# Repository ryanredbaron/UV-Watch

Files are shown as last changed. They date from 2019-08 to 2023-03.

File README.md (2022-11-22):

# UV Watch
## Current MVP
- 10 hours of battery
- Track UV/% burned
- Close enough battery tracking
 
## Project List
1. [x] Clock refinement 
2. [x] Battery shut off
3. [x] Sunscreen apply
4. [ ] Sun reset
5. [x] Less sensitive to sun 
6. [?] Uv sensor voltage revamp
7. [x] Low power mode
8. [x] Input time from PC

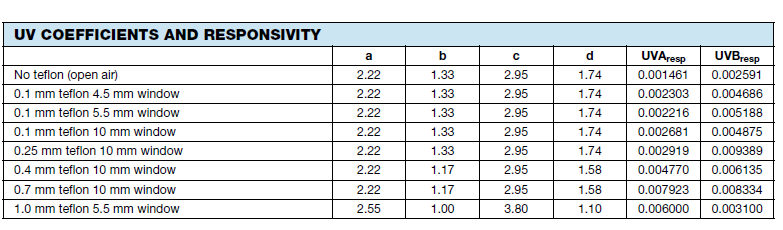
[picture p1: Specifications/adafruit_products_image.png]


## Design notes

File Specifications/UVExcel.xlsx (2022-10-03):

UV | TTB Min | TTB sec |  | y = -267.48x + 3913.6
0 | 60 | 3600 | 1000 | 27.77777778%
1 | 60 | 3600 | 1000 | 27.77777778%
2 | 60 | 3600 | 1000 | 27.77777778%
3 | 40 | 2400 | 1000 | 41.66666667%
4 | 40 | 2400 | 1000 | 41.66666667%
5 | 40 | 2400 | 1000 | 41.66666667%
6 | 30 | 1800 | 1000 | 55.55555556%
7 | 30 | 1800 | 1000 | 55.55555556%
8 | 20 | 1200 | 1000 | 83.33333333%
9 | 20 | 1200 | 1000 | 83.33333333%
10 | 20 | 1200 | 1000 | 83.33333333%
11 | 15 | 900 | 1000 | 111.1111111%
UV | TTB Sec
0 | 3913.6
1 | 3646.12 | 121.5373333
2 | 3378.64
3 | 3111.16
4 | 2843.68
5 | 2576.2
6 | 2308.72
7 | 2041.24
8 | 1773.76
9 | 1506.28
10 | 1238.8
11 | 971.32
12 | 703.84
30

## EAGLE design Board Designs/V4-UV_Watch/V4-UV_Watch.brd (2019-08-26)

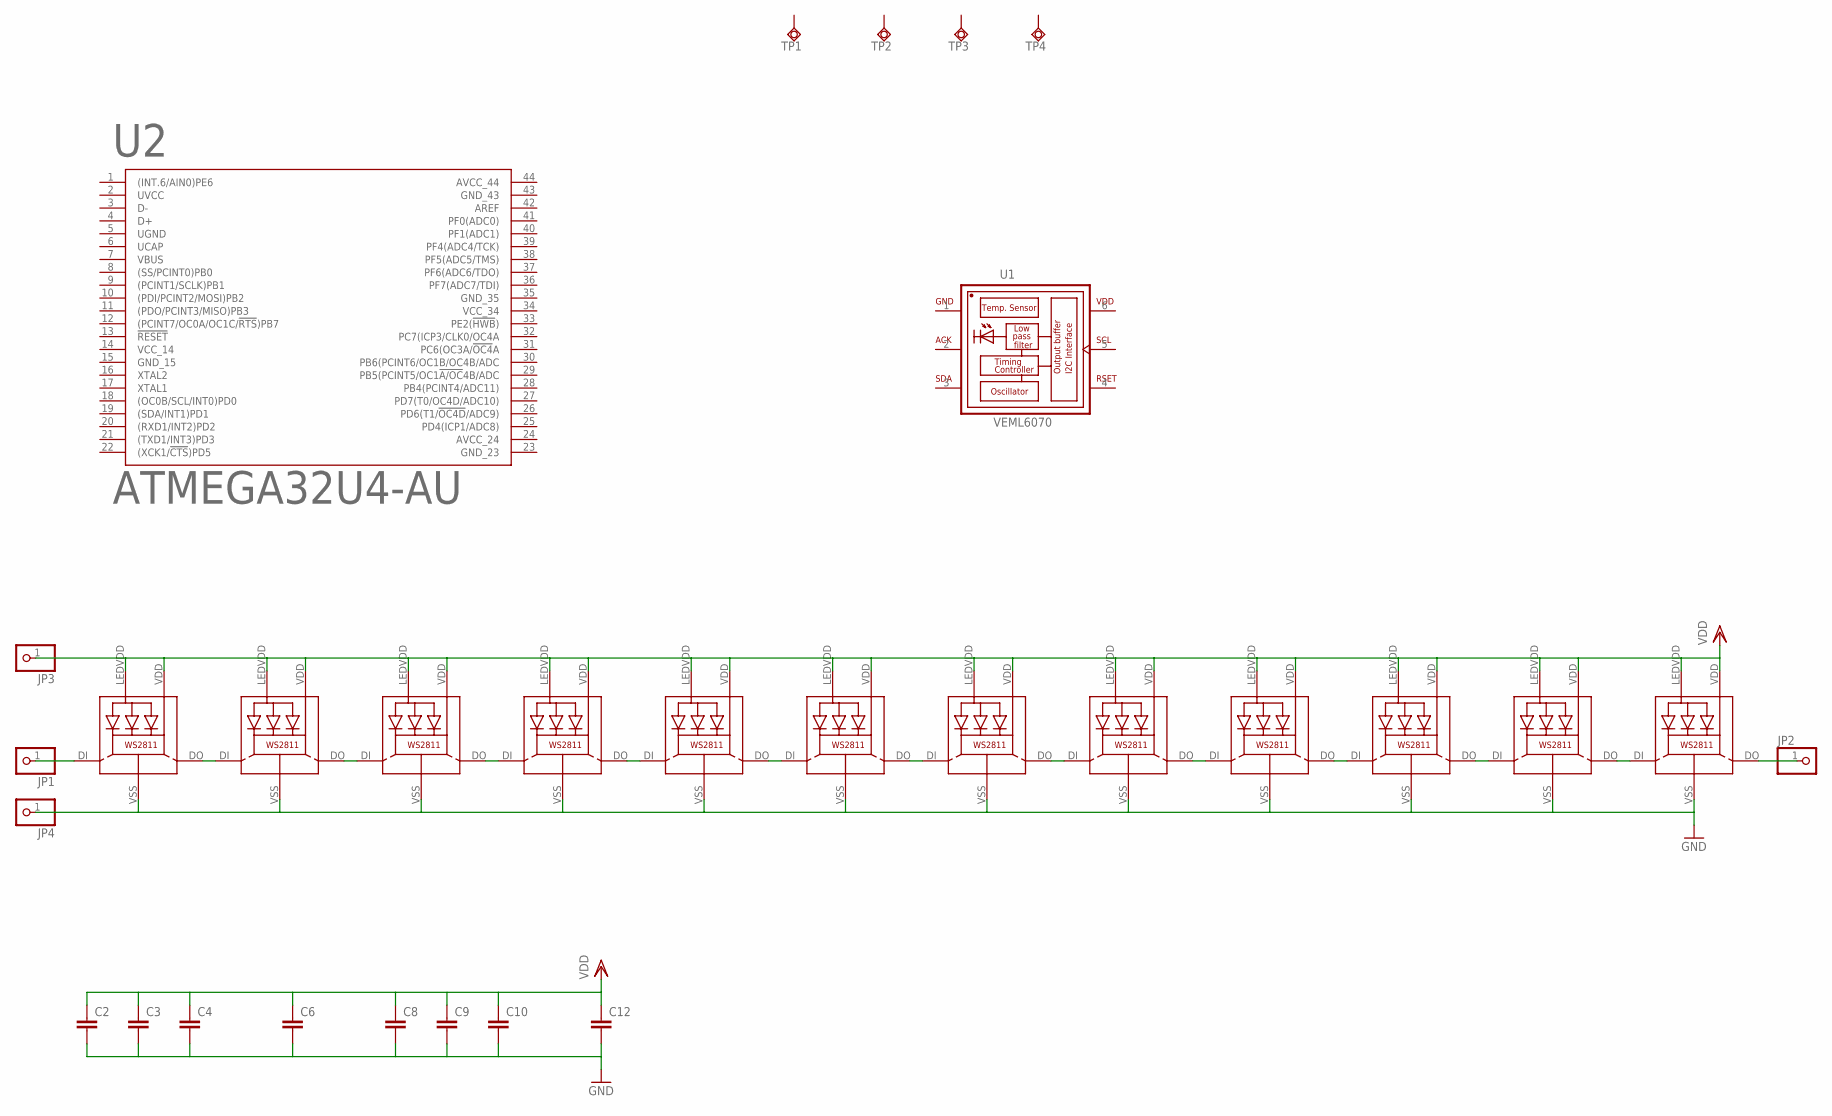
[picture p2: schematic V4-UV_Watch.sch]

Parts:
C2, C3, C4, C6, C8, C9, C10, C12: C-EUC0603; C0603
JP1, JP2, JP3, JP4: PINHD-1X1CB; 1X01-CLEANBIG
LED1, LED2, LED3, LED4, LED5, LED6, LED7, LED8, LED9, LED10, LED11, LED12: WS28115050
TP1, TP2, TP3, TP4: TESTPAD_TPSQTP20SQ; TESTPAD_TP20SQ
U1: VEML6070; PHODET_VEML6070
U2: ATMEGA32U4-AU; 44-TQFP

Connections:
AVCC_24: U2.24 (AVCC_24)
AVCC_44: U2.44 (AVCC_44)
GND: C2.2, C3.2, C4.2, C6.2, C8.2, C9.2, C10.2, C12.2, JP4.1, LED1.VSS (GND), LED2.VSS (GND), LED3.VSS (GND), LED4.VSS (GND), LED5.VSS (GND), LED6.VSS (GND), LED7.VSS (GND), LED8.VSS (GND), LED9.VSS (GND), LED10.VSS (GND), LED11.VSS (GND), LED12.VSS (GND), U1.1 (GND)
GND_15: U2.15 (GND_15)
GND_23: U2.23 (GND_23)
GND_35: U2.35 (GND_35)
GND_43: U2.43 (GND_43)
unnamed: LED1.DO, LED2.DI
unnamed: LED2.DO, LED3.DI
unnamed: LED3.DO, LED4.DI
unnamed: LED4.DO, LED5.DI
unnamed: LED5.DO, LED6.DI
unnamed: LED6.DO, LED7.DI
unnamed: LED7.DO, LED8.DI
unnamed: LED8.DO, LED9.DI
unnamed: LED9.DO, LED10.DI
unnamed: LED10.DO, LED11.DI
unnamed: LED11.DO, LED12.DI
unnamed: JP1.1, LED1.DI
unnamed: JP2.1, LED12.DO
UCAP: U2.6 (UCAP)
UGND: U2.5 (UGND)
UVCC: U2.2 (UVCC)
VCC_14: U2.14 (VCC_14)
VCC_34: U2.34 (VCC_34)
VDD: C2.1, C3.1, C4.1, C6.1, C8.1, C9.1, C10.1, C12.1, JP3.1, LED1.LEDVDD, LED1.VDD, LED2.LEDVDD, LED2.VDD, LED3.LEDVDD, LED3.VDD, LED4.LEDVDD, LED4.VDD, LED5.LEDVDD, LED5.VDD, LED6.LEDVDD, LED6.VDD, LED7.LEDVDD, LED7.VDD, LED8.LEDVDD, LED8.VDD, LED9.LEDVDD, LED9.VDD, LED10.LEDVDD, LED10.VDD, LED11.LEDVDD, LED11.VDD, LED12.LEDVDD, LED12.VDD, U1.6 (VDD)

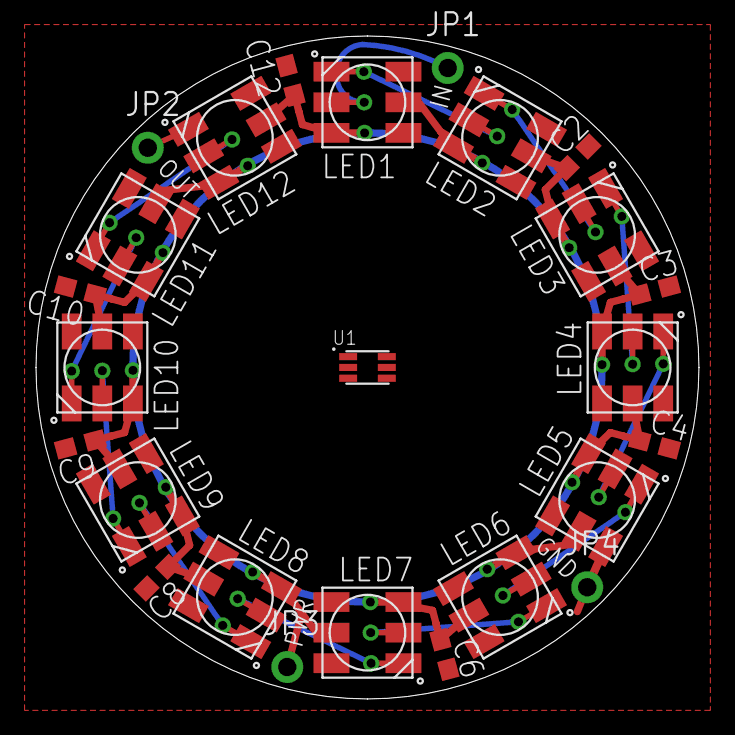
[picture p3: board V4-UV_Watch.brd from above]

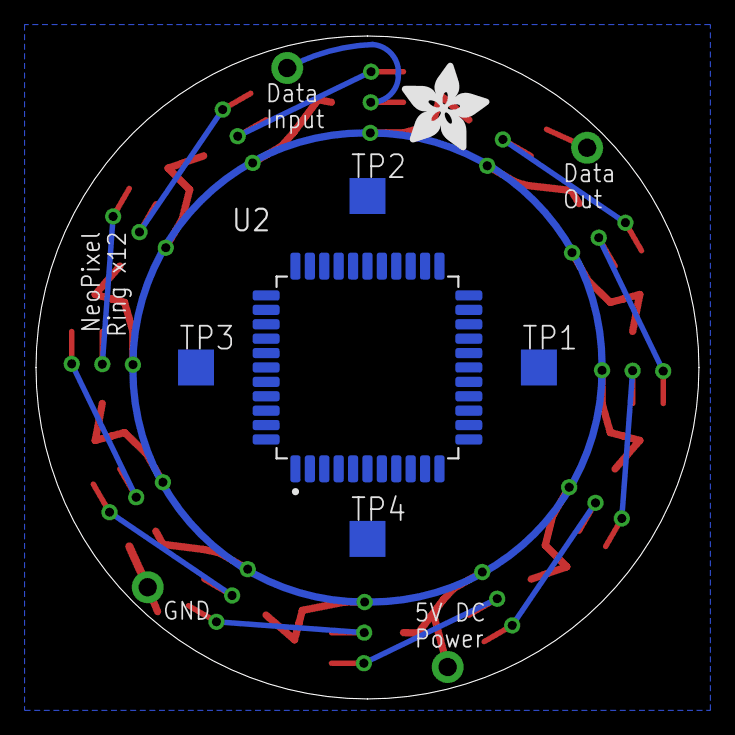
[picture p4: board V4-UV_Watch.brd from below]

Board: 2 copper layers, 36.8 x 36.8 mm, 33 parts (6 on the bottom side), 15 nets.

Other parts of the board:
U$1, U$2: GUIDE-STAR-12
U$3: ADAFRUIT_5MM

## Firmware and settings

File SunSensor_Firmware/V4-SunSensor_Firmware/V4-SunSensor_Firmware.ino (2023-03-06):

#include <tinyNeoPixel.h>
#include "TinyI2CMaster.h"

#include <avr/sleep.h>

#include "myVals.h"

//------------------Watch Variables-------------
//y = -267.48x + 3913.6
//Given "x" UV level, "y" returns seconds needed to burn, we measure time spent in "x" and calc a "% burned"
//(Time Spent at UV level)/(-267.48*(UV level)+3913.6) + ((Time Spent at UV level)/(-267.48*(UV level)+3913.6))*ginger index
//1 = ginger. Increase to burn faster, decrease to be a beautiful tan person
//default is 1
float GingerIndex = 1;
//Input SPF used
//default is 30
float SPFIndex = 30;
//How long you expect your sunscreen to last in seconds
//default is 3600
int SunScreenDurationSeconds = 3600;
//How fast you want to recover from sunburn
//Percent decay per second, as a decimal
//Default = 0.005
float BurnDecay = 0.005;
//Mode control, what we want to start on
//default is 1
int WatchModeSelect = 1;
//Sub-Mode control, what we want to start on
//default is 1
int WatchSubModeSelect = 1;
//LED Brightness
int LEDBrigthness = 5;
int adjustableLEDBrigthness = LEDBrigthness;

//------------------SunBurn Algo Setup-------------
//we assume the person isn't wearing sunscreen (BOOOOO!)
bool SunScreenApplied = false;
//Variables to help calculate
int SunScreenTTBTimer = SunScreenDurationSeconds;
float PercentBurned = 0;
float DisplayPercentBurned = 0;
float SecondsToBurn = 0;
float PercentAddedToBurn = 0;
//Average UV stuffs.
const int UVnumReadings = 50;
float UVreadings[UVnumReadings];
int UVreadIndex = 0;
float UVtotal = 0;
float UVaverage = 0;
int SecondsInSun = 0;
float CurrentReading = 0;
float PreviousReading = 0;

//------------------UV Sensor Setup-------------
// Adafruit says voltage/0.1V = UV index
// GUVA-S12SD sensor attached to this pin - voltage is 4.3 x diode photocurrent
#define UV_PIN PIN_PA2
float counts;
float UVSensorVoltage;
float voltageoffset = 0.30;

//------------------NeoPixels Setup----------------
// NeoPixel Pin
#define NEO_PIN PIN_PA3
//Count of NeoPixels
#define NUMPIXELS 12
//Setup Neopixels
tinyNeoPixel pixels = tinyNeoPixel(NUMPIXELS, NEO_PIN, NEO_GRB + NEO_KHZ800);
int RedLEDTimer = 0;
int GreenLEDTimer = 0;
int BlueLEDTimer = 0;
float TotalLEDs = NUMPIXELS;
int NeoPixelArray[NUMPIXELS][3];

//------------------Accel Setup-------------
//Initialize accel, setting up
extern int8_t accelInit();
//Run in accel.ino, not used here
extern void accelRead();
//changes global variable ZeroAtTwelve BOOL (int) 0-1
extern bool orientDisplay();
//Setup comms
#define I2C_WRITE 0
// Accel values
uint16_t aOrient;
//Check if accel is available
uint8_t gotAccel = 0;
uint16_t aShake;
uint16_t notMoving = 0;
uint8_t ZeroAtTwelve = 0;

//------------------Button Setup-------------
// Buttons - use "INPUT_PULLUP" - pins will be low when pressed
#define UPPER_BUTTON PIN_PA4
#define LOWER_BUTTON PIN_PA7
bool UpperButtonPressed = false;
bool LowerButtonPressed = false;
int UpperButtonPressedTimer = 0;
int LowerButtonPressedTimer = 0;

//------------------Voltage Setup-------------
#define BATT_READ PIN_PA1
float BatteryVoltage;
float BatteryVoltageRing;
int LowVoltageCount = 0;
float BatteryChargeVoltage = 3.5;
float MaxCutoffVoltage = 4;
float MinCutoffVoltage = 3.7;

//------------------Vibrator Setup-------------
#define VIBE_LED PIN_PA5

//---------------Alex's Clock-------------
unsigned long startMillis;
unsigned long currentMillis;
const unsigned long period = 1000;
int ClockSecond = ExtClockSecond;
int ClockMinute = ExtClockMinute;
int ClockHour = ExtClockHour;
int ErrorTime = 0;
unsigned long cumuErrorTime = 0;

void setup() {
  if (ClockHour >= 12) {
    ClockHour = 0;
  }
  Serial.begin(9600);
  Serial.println();
  Serial.println();
  Serial.println("UV Watch");
  Serial.println();

  TinyI2C.init();

  pixels.begin();
  pixels.setBrightness(LEDBrigthness);

  gotAccel = accelInit();

  pinMode(UPPER_BUTTON, INPUT_PULLUP);
  pinMode(LOWER_BUTTON, INPUT_PULLUP);

  pinMode(VIBE_LED, OUTPUT);
  digitalWrite(VIBE_LED, 1);
  delay(500);
  digitalWrite(VIBE_LED, 0);

  startMillis = millis();
}

//------Just don't edit any of this OK?-----
int LoopDelay = 5;

int InputTimer = 0;
int InputTimerTrigger = 2;

int SensorCaptureTimer = 0;
int SensorCaptureTrigger = 20;

int DisplayTimer = 0;
int DisplayTimerTrigger = 20;

int CalcTimer = 0;
int CalcTimerTrigger = 200;
//------------------------------------------


void loop() {
  SensorCaptureTimer++;
  DisplayTimer++;
  InputTimer++;
  CalcTimer++;

  currentMillis = millis();
  if (currentMillis - startMillis >= period) {

    ErrorTime = (period) - (currentMillis - startMillis);
    cumuErrorTime = cumuErrorTime - ErrorTime + 2;
    if (cumuErrorTime >= period && ClockSecond < 58) {
      ClockSecond++;
      cumuErrorTime = cumuErrorTime - period;
    }
    ClockSecond++;

    startMillis = currentMillis;

    if (ClockSecond >= 60) {
      ClockSecond = 0;
      ClockMinute++;
      if (ClockMinute >= 60) {
        ClockMinute = 0;
        ClockHour++;
        if (ClockHour >= 12) {
          ClockHour = 0;
        }
      }
    }
  }

  //---------------------------------------INPUT CAPTURE-----------------------------------------
  if (InputTimer >= InputTimerTrigger) {
    orientDisplay();

    if (digitalRead(UPPER_BUTTON)) {
      UpperButtonPressedTimer++;
    } else {
      digitalWrite(VIBE_LED, 0);
      if (UpperButtonPressedTimer > 0 && UpperButtonPressedTimer < 1000) {
        digitalWrite(VIBE_LED, 1);
        WatchModeSelect++;
        WatchSubModeSelect = 1;
      }
      UpperButtonPressedTimer = 0;
    }

    if (digitalRead(LOWER_BUTTON)) {
      LowerButtonPressedTimer++;
    } else {
      digitalWrite(VIBE_LED, 0);
      if (LowerButtonPressedTimer > 0 && LowerButtonPressedTimer < 1000) {
        digitalWrite(VIBE_LED, 1);
        WatchSubModeSelect++;
      }
      LowerButtonPressedTimer = 0;
    }
    //----DO NOT REMOVE----
    InputTimer = 0;
    //----DO NOT REMOVE----
  }
  //---------------------------------------------------------------------------------------------




  //-----------------------------------------SENSOR CAPTURE----------------------------------------
  if (SensorCaptureTimer >= SensorCaptureTrigger) {
    counts = analogRead(UV_PIN);
    UVSensorVoltage = (((counts * 3300 * 5) / 1024)) * voltageoffset;
    CurrentReading = ((UVSensorVoltage - 108) / 97);
    if (CurrentReading > 12) {
      CurrentReading = 12;
    }
    if (CurrentReading < 0.2) {
      CurrentReading = 0;
    }

    //Giving momentum to decreasing readings. Prevents shade bias. Slows down decay.
    if (CurrentReading > PreviousReading) {
      for (int i = 0; i < UVnumReadings; i++) {
        UVreadings[i] = CurrentReading;
      }
      UVtotal = CurrentReading * UVnumReadings;
    } else {
      CurrentReading = PreviousReading - ((PreviousReading - CurrentReading) / 10);
    }
    PreviousReading = CurrentReading;

    UVtotal = UVtotal - UVreadings[UVreadIndex];
    UVreadings[UVreadIndex] = CurrentReading;
    UVtotal = UVtotal + UVreadings[UVreadIndex];
    UVreadIndex++;
    if (UVreadIndex >= UVnumReadings) {
      UVreadIndex = 0;
    }
    //adjustableLEDBrigthness = (LEDBrigthness * (CurrentReading * 2)) + LEDBrigthness;
    adjustableLEDBrigthness = map(CurrentReading, 0, 12, 2, 255);
    pixels.setBrightness(adjustableLEDBrigthness);

    BatteryVoltage = (map(analogRead(BATT_READ), 0, 1024, 0, 660));
    //BatteryVoltage = 400;
    BatteryVoltageRing = (map(BatteryVoltage, 330, 400, 0, 12));
    BatteryVoltage = BatteryVoltage / 100;
    if (BatteryVoltage >= BatteryChargeVoltage && BatteryVoltage <= MinCutoffVoltage) {
      LowVoltageCount++;
      if (LowVoltageCount >= 100) {
        pixels.clear();
        pixels.show();
        sleep_enable();
        set_sleep_mode(SLEEP_MODE_PWR_DOWN);
        sleep_cpu();
      }
    }

    //----DO NOT REMOVE----
    SensorCaptureTimer = 0;
    //----DO NOT REMOVE----
  }
  //---------------------------------------------------------------------------------------------




  //-----------------------------------------CALC------------------------------------------------
  if (CalcTimer >= CalcTimerTrigger) {
    if (SunScreenApplied == true) {
      SunScreenTTBTimer--;
      if (SunScreenTTBTimer == 0) {
        SunScreenApplied = false;
      }
    }
    UVaverage = UVtotal / UVnumReadings;
    if (UVaverage < 0.1) {
      //If we see no UV
      UVaverage = 0;
      if (PercentBurned > 0) {
        //Decay percent burned by .1%/Second when no UV
        PercentBurned = PercentBurned - BurnDecay;
      } else {
        //When back to zero, reset all. No burn.
        SecondsInSun = 0;
      }
    } else {
      //If we see UV, start counting time in sun
      SecondsInSun++;
      //If sunscreen applied. Start counting down and dividing time to burn by SPFIndex
      if (SunScreenApplied == true) {
        //Math with sunscreen
        SecondsToBurn = (-267.48 * UVaverage + 3913.6) * SPFIndex;
      } else {
        //Math without sunscreen
        SecondsToBurn = -267.48 * UVaverage + 3913.6;
      }
      //Building the new "% burned".
      PercentAddedToBurn = (1 / SecondsToBurn) * 100;
      PercentBurned = PercentBurned + (PercentAddedToBurn * GingerIndex);
    }

    //Value catching. Dealing with float. Makes 0- = 0
    if (PercentBurned < 0) {
      PercentBurned = 0;
    }
    if (PercentBurned > 200) {
      PercentBurned = 200;
    }

    /*
    //Testing/monitoring
    Serial.print("Average UV - ");
    Serial.println(UVaverage);
    Serial.print("% burned - ");
    Serial.println(PercentBurned);
    Serial.print("Seconds in sun - ");
    Serial.println(SecondsInSun);
    if (CurrentReading != 0) {
      Serial.print("Time to Burn (min)- ");
      Serial.println(((100 / PercentBurned) * SecondsInSun) / 60);
    }
    Serial.print("Sunscreen applied? - ");
    Serial.println(SunScreenApplied ? "Applied" : "None");
    if (SunScreenApplied) {
      Serial.print("Sunscreen left - ");
      Serial.println(SunScreenTTBTimer);
    }
    Serial.println("----------------");
    */

    //----DO NOT REMOVE----
    CalcTimer = 0;
    //----DO NOT REMOVE----
  }
  //---------------------------------------------------------------------------------------------




  //------------------------------------------DISPLAY----------------------------------------------
  if (DisplayTimer >= DisplayTimerTrigger) {
    switch (WatchModeSelect) {
      case 1:
        switch (WatchSubModeSelect) {
          case 1:
            if (!ZeroAtTwelve) {
              break;
            }
            //Percent burned display
            for (float PixelLocation = 0; PixelLocation < TotalLEDs; PixelLocation++) {
              //Check if we are over 100% burned
              if (PercentBurned < 100) {
                DisplayPercentBurned = PercentBurned;
              } else {
                //if we are, then subtract 100 to display correctly
                DisplayPercentBurned = PercentBurned - 100;
              }
              //If we've reached 2x burned, pray for God
              if (PercentBurned == 200) {
                NeoPixelArray[0][0] = 255;
                NeoPixelArray[3][0] = 255;
                NeoPixelArray[6][0] = 255;
                NeoPixelArray[9][0] = 255;
              }
              //only enter here if the current pixel we care about is active in the loop
              if (PixelLocation == int(TotalLEDs * (DisplayPercentBurned / 100))) {
                if (PercentBurned < 100) {
                  //If we aren't over burned, show normally.
                  RedLEDTimer = 255 * (PixelLocation / TotalLEDs);
                  GreenLEDTimer = 255 - RedLEDTimer;
                  BlueLEDTimer = 0;
                } else {
                  //If we are over burned then show red
                  RedLEDTimer = 255;
                  GreenLEDTimer = 0;
                  BlueLEDTimer = 0;
                  NeoPixelArray[int(PixelLocation - 1)][0] = RedLEDTimer;
                  NeoPixelArray[int(PixelLocation - 1)][1] = GreenLEDTimer + 40;
                  NeoPixelArray[int(PixelLocation - 1)][2] = BlueLEDTimer;
                  NeoPixelArray[int(PixelLocation - 2)][0] = RedLEDTimer;
                  NeoPixelArray[int(PixelLocation - 2)][1] = GreenLEDTimer + 80;
                  NeoPixelArray[int(PixelLocation - 2)][2] = BlueLEDTimer;
                }
                NeoPixelArray[int(PixelLocation)][0] = RedLEDTimer;
                NeoPixelArray[int(PixelLocation)][1] = GreenLEDTimer;
                NeoPixelArray[int(PixelLocation)][2] = BlueLEDTimer;
                if (SunScreenApplied) {
                  for (int i = 0; i < (SunScreenTTBTimer / 900) + 1; i++) {
                    PixelLocation++;
                    if (PixelLocation < 12) {
                      NeoPixelArray[int(PixelLocation)][0] = 0;
                      NeoPixelArray[int(PixelLocation)][1] = 0;
                      NeoPixelArray[int(PixelLocation)][2] = 255;
                    } else {
                      NeoPixelArray[int(PixelLocation - 12)][0] = 0;
                      NeoPixelArray[int(PixelLocation - 12)][1] = 0;
                      NeoPixelArray[int(PixelLocation - 12)][2] = 255;
                    }
                  }
                }
              }
            }
            break;  //----DO NOT REMOVE----
          case 2:
            //UV level display
            for (float PixelLocation = 0; PixelLocation < TotalLEDs; PixelLocation++) {
              if (PixelLocation <= UVaverage) {
                RedLEDTimer = 255 * (PixelLocation / TotalLEDs);
                GreenLEDTimer = 0;
                BlueLEDTimer = 255 - RedLEDTimer;
                NeoPixelArray[int(PixelLocation)][0] = RedLEDTimer;
                NeoPixelArray[int(PixelLocation)][1] = GreenLEDTimer;
                NeoPixelArray[int(PixelLocation)][2] = BlueLEDTimer;
              }
            }
            break;  //----DO NOT REMOVE----
          default:
            WatchSubModeSelect = 1;
            break;  //----DO NOT REMOVE----
        }
        break;  //----DO NOT REMOVE----
      case 2:
        switch (WatchSubModeSelect) {
          case 1:
            if (!ZeroAtTwelve) {
              break;
            }
            //Watch mode
            for (float PixelLocation = 0; PixelLocation < TotalLEDs; PixelLocation++) {
              if (PixelLocation == map(ClockSecond, 0, 60, 0, 12)) {
                NeoPixelArray[int(PixelLocation)][0] = 255;
              }
              if (PixelLocation == map(ClockMinute, 0, 60, 0, 12)) {
                NeoPixelArray[int(PixelLocation)][1] = 255;
              }
              if (PixelLocation == ClockHour) {
                NeoPixelArray[int(PixelLocation)][2] = 255;
              }
            }
            break;  //----DO NOT REMOVE----
          case 2:
            for (float PixelLocation = 0; PixelLocation < TotalLEDs; PixelLocation++) {
              if (PixelLocation == map(abs(ErrorTime), 0, 50, 0, 12)) {
                if (ErrorTime < 0) {
                  NeoPixelArray[int(PixelLocation)][0] = 255;
                } else {
                  NeoPixelArray[int(PixelLocation)][1] = 255;
                }
              }
            }
            break;
          case 3:
            for (float PixelLocation = 0; PixelLocation < TotalLEDs; PixelLocation++) {
              if (PixelLocation < map(abs(cumuErrorTime), 0, 1000, 0, 12)) {
                NeoPixelArray[int(PixelLocation)][0] = 255;
              }
            }
            break;
          default:
            WatchSubModeSelect = 1;
            break;  //----DO NOT REMOVE----
        }
        break;
      case 3:
        switch (WatchSubModeSelect) {
          case 1:
            //Battery voltage
            for (float PixelLocation = 0; PixelLocation < TotalLEDs; PixelLocation++) {
              if (PixelLocation < BatteryVoltageRing) {
                if (PixelLocation <= MinCutoffVoltage) {
                  NeoPixelArray[int(PixelLocation)][0] = 255;
                  NeoPixelArray[int(PixelLocation)][1] = 0;
                  NeoPixelArray[int(PixelLocation)][2] = 0;
                } else {
                  NeoPixelArray[int(PixelLocation)][0] = 255;
                  NeoPixelArray[int(PixelLocation)][1] = 255;
                  NeoPixelArray[int(PixelLocation)][2] = 255;
                }
              }
            }
            break;  //----DO NOT REMOVE----
          case 2:
            //Red flashlight
            for (float PixelLocation = 0; PixelLocation < TotalLEDs; PixelLocation++) {
              NeoPixelArray[int(PixelLocation)][0] = 255;
              NeoPixelArray[int(PixelLocation)][1] = 0;
              NeoPixelArray[int(PixelLocation)][2] = 0;
            }
            pixels.setBrightness(255);
            break;  //----DO NOT REMOVE----
          case 3:
            //White-ish flashlight
            for (float PixelLocation = 0; PixelLocation < TotalLEDs; PixelLocation++) {
              NeoPixelArray[int(PixelLocation)][0] = 175;
              NeoPixelArray[int(PixelLocation)][1] = 255;
              NeoPixelArray[int(PixelLocation)][2] = 255;
            }
            pixels.setBrightness(255);
            break;  //----DO NOT REMOVE----
          case 4:
            //Party time, excellent
            RedLEDTimer = random(0, 200);
            GreenLEDTimer = random(0, 200);
            BlueLEDTimer = random(0, 200);
            for (float PixelLocation = 0; PixelLocation < TotalLEDs; PixelLocation++) {
              NeoPixelArray[int(PixelLocation)][0] = RedLEDTimer;
              NeoPixelArray[int(PixelLocation)][1] = GreenLEDTimer;
              NeoPixelArray[int(PixelLocation)][2] = BlueLEDTimer;
            }
            pixels.setBrightness(random(0, 255));
            break;  //----DO NOT REMOVE----
          default:
            WatchSubModeSelect = 1;
            break;  //----DO NOT REMOVE----
        }
        break;  //----DO NOT REMOVE----
      case 4:
        switch (WatchSubModeSelect) {
          //Apply sunscreen question
          case 1:
            NeoPixelArray[0][2] = 255;
            NeoPixelArray[3][2] = 255;
            NeoPixelArray[6][2] = 255;
            NeoPixelArray[9][2] = 255;
            break;
          case 2:
            //Apply sunscreen
            SunScreenApplied = true;
            SunScreenTTBTimer = SunScreenDurationSeconds;
            WatchModeSelect = 1;
            WatchSubModeSelect = 1;
            break;
          default:
            WatchSubModeSelect = 1;
            break;  //----DO NOT REMOVE----
        }
        break;
      default:
        WatchModeSelect = 1;
        break;  //----DO NOT REMOVE----
    }
    //Loop through all color selections and display
    for (int PixelLocation = 0; PixelLocation < TotalLEDs; PixelLocation++) {
      pixels.setPixelColor(PixelLocation, pixels.Color(NeoPixelArray[PixelLocation][0], NeoPixelArray[PixelLocation][1], NeoPixelArray[PixelLocation][2]));
      NeoPixelArray[PixelLocation][0] = 0;
      NeoPixelArray[PixelLocation][1] = 0;
      NeoPixelArray[PixelLocation][2] = 0;
      delay(1);
    }
    pixels.show();
    //----DO NOT REMOVE----
    DisplayTimer = 0;
    //----DO NOT REMOVE----
  }
  //---------------------------------------------------------------------------------------------




  delay(LoopDelay);
}

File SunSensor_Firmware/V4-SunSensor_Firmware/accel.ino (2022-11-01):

extern uint16_t aOrient;
extern uint8_t  gotAccel;
extern uint16_t aShake;
extern uint16_t notMoving;

#define ACCELaddress 0x15        // I2C address

// Write a register select to accelerometer

uint8_t wrAccel(uint8_t reg) {
  TinyI2C.start(ACCELaddress, I2C_WRITE);
  TinyI2C.write(reg);
  TinyI2C.stop();
  return 1;
}

// Write a register select and data to accelerometer

uint8_t wrAccel2(uint8_t reg, uint8_t dat) {
  TinyI2C.start(ACCELaddress, I2C_WRITE);
  TinyI2C.write(reg);
  TinyI2C.write(dat);
  TinyI2C.stop();
  return 1;
}

// Read accel value (32 bits) from accelerometer

uint16_t rdAccel() {
   uint8_t rdbuffer[2] = {0x55,0x55};

  TinyI2C.start(ACCELaddress, 2);
  rdbuffer[0] = TinyI2C.read();
  rdbuffer[1] = TinyI2C.read();
  TinyI2C.stop();
  
  return ( (rdbuffer[0] << 4) | (rdbuffer[1] >> 4));
}

// See if MXC4005XC accelerometer is present and initialize

int8_t accelInit() {
  uint16_t id = 0;

  TinyI2C.start(ACCELaddress, 0);
  TinyI2C.write(0x0E);
  TinyI2C.restart(ACCELaddress, 1);
  id = TinyI2C.read();
  TinyI2C.stop();
  wrAccel2(0x0C, 0x80);      // Set shake mode
  return id;
  
//  wrAccel(0x0E);  
//  
//  TinyI2C.start(ACCELaddress, 1);
//  id = TinyI2C.read();
//
//  if (id != 0x02) {
//        return 0;
//  }
//
//  wrAccel2(0x0C, 0x80);      // Set shake mode
//  return 1;
}

// Read accelerometer

void accelRead() {
  wrAccel(0x02);
  aOrient = rdAccel();
  wrAccel(0x00);
  aShake = rdAccel();
  wrAccel2(0x00, 0xCF);   // Clear change and shake interrupt bits     
}

bool orientDisplay() {

  accelRead();

  // ORIXY[1] ORIXY[0] Orientation
  //   0       0        +X
  //   0       1        +Y
  //   1       0        -X
  //   1       1        -Y
  
  if ( (aOrient & 0x30) == 0x00) ZeroAtTwelve = 1;          // +X
  if ( (aOrient & 0x30) == 0x20) ZeroAtTwelve = 0;          // -X

  return( (aShake & 0xC00) == 0);           // 0 == No change in XY or Z
}

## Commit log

2019-08-12 Initial Load
    [Eagle-V2-SunSensor.brd, Eagle-V2-SunSensor.sch, SunSensor.dsn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]
2019-08-25 adding eagle files
    [Adafruit NeoPixel Ring 12.brd, Adafruit NeoPixel Ring 12.sch, SunSensor.dsn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]
2019-08-25 V4 hardware
    [V4-UV_Watch.brd, V4-UV_Watch.sch]
2019-08-26 New board design
    [V4-UV_Watch.brd, V4-UV_Watch.sch]
2022-09-28 reading adjustments
    [UVExcel.xlsx]
2022-10-03 adding sunscreen
    [UVExcel.xlsx]
2022-11-01 Mocap testing
    [UVexcel2.xlsx]
2022-11-10 voltage ref change
    [UVexcel2.xlsx]
2022-11-15 Changing LED update method
2022-11-19 File structure update
    [UVExcel.xlsx, UVexcel2.xlsx]
2022-11-21 voltage cutoff, input from PC

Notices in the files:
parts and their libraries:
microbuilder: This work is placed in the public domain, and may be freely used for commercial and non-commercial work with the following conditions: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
